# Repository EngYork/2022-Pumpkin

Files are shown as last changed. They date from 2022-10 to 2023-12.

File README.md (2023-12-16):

A Pumpkin-shaped lamp using WS2812b LED modules and the cheapest STM32 I could find on Digikey.

The timings are generated - and data fed fast enough - by using the DMA and abusing the SPI (See 2022 Pumpkin Code for details).

Due to component shortages the FTDI USB chip was never fitted or tested by me, although someone told me they tried it and it didn't work - so beware of that.

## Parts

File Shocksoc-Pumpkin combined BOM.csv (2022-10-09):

Standard
Source: | /home/david/Desktop/Pumpkin-main/Shocksoc-Pumpkin.kicad_sch
Date: | Wed 21 Sep 2022 12:20:54 BST
Tool: | Eeschema (6.0.7)
Generator: | /usr/share/kicad/plugins/bom_csv_grouped_by_value_with_fp.py
Component Count: | 44
Ref | Qnty | Value | Cmp name | Footprint | Description
C1, C3, C4, C7, | 4 | 10n | C | Capacitor_SMD:C_0805_2012Metric_Pad1.18x1.45mm_HandSolder | Unpolarized capacitor
C2, C8, | 2 | 1u | C | Capacitor_SMD:C_0805_2012Metric_Pad1.18x1.45mm_HandSolder | Unpolarized capacitor
C5, | 1 | 4u7 | C_Polarized | Capacitor_SMD:C_0805_2012Metric_Pad1.18x1.45mm_HandSolder | Polarized capacitor
D1, D2, D3, D4, D5, D6, D7, D8, D9, D10, D11, D12, D13, D14, D15, D16, D17, D18, D19, D20, | 20 | WS2813B | WS2813B_8 | LED_SMD:LED_WS2812_PLCC6_5.0x5.0mm_P1.6mm | RGB LED with integrated controller
J1, | 1 | USB_B_Micro | USB_B_Micro | Connector_USB:USB_Micro-B_Molex-105133-0001 | USB Micro Type B connector
J2, | 1 | Conn_01x03_Male | Conn_01x03_Male | Connector_PinHeader_2.54mm:PinHeader_1x03_P2.54mm_Vertical | Generic connector, single row, 01x03, script generated (kicad-library-utils/schlib/autogen/connector/)
J3, | 1 | Conn_01x02_Male | Conn_01x02_Male | Connector_PinHeader_2.54mm:PinHeader_1x02_P2.54mm_Vertical | Generic connector, single row, 01x02, script generated (kicad-library-utils/schlib/autogen/connector/)
J4, | 1 | Conn_ARM_JTAG_SWD_10 | Conn_ARM_JTAG_SWD_10 | Connector_PinHeader_1.27mm:PinHeader_2x05_P1.27mm_Vertical_SMD | Cortex Debug Connector, standard ARM Cortex-M SWD and JTAG interface
JP1, JP2, | 2 | SolderJumper_2_Open | SolderJumper_2_Open | Jumper:SolderJumper-2_P1.3mm_Open_RoundedPad1.0x1.5mm | Solder Jumper, 2-pole, open
Q1, | 1 | BSN20 | BSN20 | Package_TO_SOT_SMD:SOT-23 | 0.5A Id, 50V Vds, N-Channel MOSFET, SOT-23
R1, R2, R3, | 3 | 10k | R | Resistor_SMD:R_0805_2012Metric_Pad1.20x1.40mm_HandSolder | Resistor
SW1, SW2, SW3, SW4, | 4 | SW_Push | SW_Push | Button_Switch_SMD:SW_Push_1P1T_NO_6x6mm_H9.5mm | Push button switch, generic, two pins
U1, | 1 | AP2202K-3.3 | AP2204K-ADJ | Package_TO_SOT_SMD:SOT-23-5 | 150mA low dropout adjustable linear regulator, wide input voltage range, SOT-23-5 package
U2, | 1 | STM32L011F4Px | STM32L011F4Px | Package_SO:TSSOP-20_4.4x6.5mm_P0.65mm | ARM Cortex-M0+ MCU, 16KB flash, 2KB RAM, 32MHz, 1.65-3.6V, 16 GPIO, TSSOP-20
U3, | 1 | FT231XQ | FT231XQ | Package_DFN_QFN:QFN-20-1EP_4x4mm_P0.5mm_EP2.5x2.5mm | Full Speed USB to Full Handshake UART, QFN-20
RP2040
Source: | /home/david/Desktop/Pumpkin-rp2040/Shocksoc-Pumpkin.kicad_sch
Date: | Wed 21 Sep 2022 14:40:01 BST
Tool: | Eeschema (6.0.7)
Generator: | /usr/share/kicad/plugins/bom_csv_grouped_by_value_with_fp.py
Component Count: | 71
Ref | Qnty | Value | Cmp name | Footprint | Description | Vendor
C1, C3, C5, C7, | 4 | 10n | C | Capacitor_SMD:C_0805_2012Metric_Pad1.18x1.45mm_HandSolder | Unpolarized capacitor
C2, C4, | 2 | 1u | C | Capacitor_SMD:C_0805_2012Metric_Pad1.18x1.45mm_HandSolder | Unpolarized capacitor
C6, | 1 | 4u7 | C_Polarized | Capacitor_SMD:C_0805_2012Metric_Pad1.18x1.45mm_HandSolder | Polarized capacitor
C8, C9, | 2 | 20p | C | Capacitor_SMD:C_0603_1608Metric_Pad1.08x0.95mm_HandSolder | Unpolarized capacitor
C10, C11, | 2 | 1u | C | Capacitor_SMD:C_0603_1608Metric_Pad1.08x0.95mm_HandSolder | Unpolarized capacitor
D1, D2, D3, D4, D5, D6, D7, D8, D9, D10, D11, D12, D13, D14, D15, D16, D17, D18, D19, D20, | 20 | WS2813B | WS2813B_8 | LED_SMD:LED_WS2812_PLCC6_5.0x5.0mm_P1.6mm | RGB LED with integrated controller
J1, | 1 | USB_B_Micro | USB_B_Micro | Connector_USB:USB_Micro-B_Molex-105133-0001 | USB Micro Type B connector
J2, | 1 | Conn_ARM_JTAG_SWD_10 | Conn_ARM_JTAG_SWD_10 | Connector_PinHeader_1.27mm:PinHeader_2x05_P1.27mm_Vertical_SMD | Cortex Debug Connector, standard ARM Cortex-M SWD and JTAG interface
J3, | 1 | Conn_01x03_Male | Conn_01x03_Male | Connector_PinHeader_2.54mm:PinHeader_1x03_P2.54mm_Vertical_SMD_Pin1Left | Generic connector, single row, 01x03, script generated (kicad-library-utils/schlib/autogen/connector/)
J4, | 1 | Conn_01x02_Male | Conn_01x02_Male | Connector_PinHeader_2.54mm:PinHeader_1x02_P2.54mm_Vertical | Generic connector, single row, 01x02, script generated (kicad-library-utils/schlib/autogen/connector/)
JP1, JP2, | 2 | SolderJumper_2_Open | SolderJumper_2_Open | Jumper:SolderJumper-2_P1.3mm_Open_RoundedPad1.0x1.5mm | Solder Jumper, 2-pole, open
Q1, | 1 | BSN20 | BSN20 | Package_TO_SOT_SMD:SOT-23 | 0.5A Id, 50V Vds, N-Channel MOSFET, SOT-23
R1, R4, | 2 | 27 | R | Resistor_SMD:R_0603_1608Metric_Pad0.98x0.95mm_HandSolder | Resistor
R2, R3, | 2 | 10k | R | Resistor_SMD:R_0805_2012Metric_Pad1.20x1.40mm_HandSolder | Resistor
SW1, SW2, SW3, SW4, | 4 | SW_Push | SW_Push | Button_Switch_SMD:SW_Push_1P1T_NO_6x6mm_H9.5mm | Push button switch, generic, two pins
TP1, TP2, TP3, TP4, TP5, TP6, TP7, TP8, TP9, TP10, TP11, TP12, TP13, TP14, TP15, TP16, TP17, TP18, TP19, TP20, TP21, | 21 | TestPoint | TestPoint | TestPoint:TestPoint_Pad_D1.0mm | test point
U1, | 1 | AP2202K-3.3 | AP2204K-ADJ | Package_TO_SOT_SMD:SOT-23-5 | 150mA low dropout adjustable linear regulator, wide input voltage range, SOT-23-5 package
U3, | 1 | W25Q32JVSS | W25Q32JVSS | Package_SO:SOIC-8_5.23x5.23mm_P1.27mm | 32Mb Serial Flash Memory, Standard/Dual/Quad SPI, SOIC-8
U4, | 1 | RP2040 | RP2040 | Package_DFN_QFN:QFN-56-1EP_7x7mm_P0.4mm_EP3.2x3.2mm | A microcontroller by Raspberry Pi
Y1, | 1 | ABM8G-106-12.000MHZ-T | Crystal_GND24 | Crystal:Crystal_SMD_Abracon_ABM8G-4Pin_3.2x2.5mm | Four pin crystal, GND on pins 2 and 4
Combined (to produce 1 of each)
Quantity |  |  |  |  | Distributor Link
8 | 10n | C | Capacitor_SMD:C_0805_2012Metric_Pad1.18x1.45mm_HandSolder | Unpolarized capacitor
6 | 1u | C | Capacitor_SMD:C_0805_2012Metric_Pad1.18x1.45mm_HandSolder | Unpolarized capacitor
2 | 4u7 | C_Polarized | Capacitor_SMD:C_0805_2012Metric_Pad1.18x1.45mm_HandSolder | Polarized capacitor
2 | 20p | C | Capacitor_SMD:C_0603_1608Metric_Pad1.08x0.95mm_HandSolder | Unpolarized capacitor
40 | WS2813B | WS2813B_8 | LED_SMD:LED_WS2812_PLCC6_5.0x5.0mm_P1.6mm | RGB LED with integrated controller
2 | USB_B_Micro | USB_B_Micro | Connector_USB:USB_Micro-B_Molex-105133-0001 | USB Micro Type B connector
2 | Conn_01x03_Male | Conn_01x03_Male | Connector_PinHeader_2.54mm:PinHeader_1x03_P2.54mm_Vertical | Generic connector, single row, 01x03, script generated (kicad-library-utils/schlib/autogen/connector/)
2 | Conn_01x02_Male | Conn_01x02_Male | Connector_PinHeader_2.54mm:PinHeader_1x02_P2.54mm_Vertical | Generic connector, single row, 01x02, script generated (kicad-library-utils/schlib/autogen/connector/)
2 | Conn_ARM_JTAG_SWD_10 | Conn_ARM_JTAG_SWD_10 | Connector_PinHeader_1.27mm:PinHeader_2x05_P1.27mm_Vertical_SMD | Cortex Debug Connector, standard ARM Cortex-M SWD and JTAG interface
2 | 27 | R | Resistor_SMD:R_0603_1608Metric_Pad0.98x0.95mm_HandSolder | Resistor
5 | 10k | R | Resistor_SMD:R_0805_2012Metric_Pad1.20x1.40mm_HandSolder | Resistor
8 | SW_Push | SW_Push | Button_Switch_SMD:SW_Push_1P1T_NO_6x6mm_H9.5mm | Push button switch, generic, two pins
2 | AP2202K-3.3 | AP2204K-ADJ | Package_TO_SOT_SMD:SOT-23-5 | 150mA low dropout adjustable linear regulator, wide input voltage range, SOT-23-5 package
1 | STM32L011F4Px | STM32L011F4Px | Package_SO:TSSOP-20_4.4x6.5mm_P0.65mm | ARM Cortex-M0+ MCU, 16KB flash, 2KB RAM, 32MHz, 1.65-3.6V, 16 GPIO, TSSOP-20
1 | FT231XQ | FT231XQ | Package_DFN_QFN:QFN-20-1EP_4x4mm_P0.5mm_EP2.5x2.5mm | Full Speed USB to Full Handshake UART, QFN-20
1 | W25Q32JVSS | W25Q32JVSS | Package_SO:SOIC-8_5.23x5.23mm_P1.27mm | 32Mb Serial Flash Memory, Standard/Dual/Quad SPI, SOIC-8
1 | RP2040 | RP2040 | Package_DFN_QFN:QFN-56-1EP_7x7mm_P0.4mm_EP3.2x3.2mm | A microcontroller by Raspberry Pi
1 | ABM8G-106-12.000MHZ-T | Crystal_GND24 | Crystal:Crystal_SMD_Abracon_ABM8G-4Pin_3.2x2.5mm | Four pin crystal, GND on pins 2 and 4

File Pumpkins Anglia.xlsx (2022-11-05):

Part Number | Manufacturer | Description | Free Stock | Quantity Required | Prices
0805B103K500CT | WALSIN TECHNOLOGY CORPORATION | 0805 50V X7R 10NF 10% | 2974400 | 150 | QTY 50:£0.00421 ■ QTY 100:£0.00409 ■ QTY 150:£0.00397 ■ QTY 300:£0.00386 ■ QTY 1050:£0.00375 ■ QTY 2050:£0.00365 ■ QTY 4000+:£0.00356
0805F105Z160CT | WALSIN TECHNOLOGY CORPORATION | 0805 16V Y5V 1UF Z% | 43750 | 100 | QTY 50:£0.0073 ■ QTY 100:£0.00708 ■ QTY 150:£0.00688 ■ QTY 300:£0.00668 ■ QTY 1050:£0.0065 ■ QTY 2050:£0.00633 ■ QTY 4000+:£0.00616
0805X475K250CT | WALSIN TECHNOLOGY CORPORATION | 0805 25V X5R 4.7UF 10% | 365600 | 50 | QTY 50:£0.01232 ■ QTY 100:£0.01195 ■ QTY 150:£0.01161 ■ QTY 200:£0.01128 ■ QTY 550:£0.01097 ■ QTY 1050:£0.01068 ■ QTY 3000+:£0.0104
M50-3500542 | HARWIN | 05+05 DIL VERT PIN HDR | 24533 | 25 | QTY 1:£0.657 ■ QTY 1001:£0.644 ■ QTY 2001+:£0.618
DMN65D8L | DIODES ZETEX | SOT23 MOSFET BVDSS 41V-60V | 50 | 30 | QTY 1+:£0.01228
CR0805-JW-103ELF | BOURNS ELECTRONICS GMBH | 0805 5% 10K 1/8W | 124900 | 100 | QTY 50:£0.00289 ■ QTY 5050:£0.00263 ■ QTY 10050+:£0.00247
ST063DR | DIPTRONICS | SM 6MM RND SW 5.0BTN 320GF T/R | 12590 | 30 | QTY 1:£0.21196 ■ QTY 901:£0.20512 ■ QTY 1801:£0.19871 ■ QTY 2701:£0.13824 ■ QTY 3601+:£0.13248
AP2202K-3.3TRG1 | DIODES ZETEX | SOT25 LDO CMOS LOWCURR | 27200 | 30 | QTY 1:£0.12283 ■ QTY 3001:£0.1196 ■ QTY 6001+:£0.11654
STM32L010F4P6 | STMICROELECTRONICS | TSSOP20 ULP ARM CORTEX-M0+ MCU | 80 | 30 | QTY 1+:£0.83

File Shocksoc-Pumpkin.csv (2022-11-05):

Source: | /home/david/Desktop/Pumpkin/Shocksoc-Pumpkin.kicad_sch
Date: | Mon 10 Oct 2022 00:04:21 BST
Tool: | Eeschema (6.0.7)
Generator: | /usr/share/kicad/plugins/bom_csv_grouped_by_value_with_fp.py
Component Count: | 34
Ref | Qnty | Value | Cmp name | Footprint | Description | Vendor
C1, C3, C4, C7, | 4 | 10n | C | Capacitor_SMD:C_0805_2012Metric_Pad1.18x1.45mm_HandSolder | Unpolarized capacitor | https://www.anglia-live.com/products/product.aspx?catalogueref=1759736001
C2, C8, | 2 | 1u | C | Capacitor_SMD:C_0805_2012Metric_Pad1.18x1.45mm_HandSolder | Unpolarized capacitor | https://www.anglia-live.com/products/product.aspx?catalogueref=1759756001
C5, | 1 | 4u7 | C_Polarized | Capacitor_SMD:C_0805_2012Metric_Pad1.18x1.45mm_HandSolder |  | https://www.anglia-live.com/products/product.aspx?catalogueref=1759772001
D1, D2, D3, D4, D5, D6, D7, D8, D9, D10, | 10 | WS2813B | WS2813B_9 | Library:LED_WS2813_hand | RGB LED with integrated controller | https://www.digikey.co.uk/en/products/detail/seeed-technology-co-ltd/601000200/8120706
J1, | 1 | USB_B_Micro | USB_B_Micro | Connector_USB:USB_Micro-B_Molex-105133-0001 | USB Micro Type B connector | https://www.digikey.co.uk/en/products/detail/molex/1051330001/3313407
J2, | 1 | Conn_01x03_Male | Conn_01x03_Male | Connector_PinHeader_2.54mm:PinHeader_1x03_P2.54mm_Vertical | Generic connector, single row, 01x03, script generated (kicad-library-utils/schlib/autogen/connector/) | NA
J3, | 1 | Conn_01x02_Male | Conn_01x02_Male | Connector_PinHeader_2.54mm:PinHeader_1x02_P2.54mm_Vertical | Generic connector, single row, 01x02, script generated (kicad-library-utils/schlib/autogen/connector/) | NA
J4, | 1 | Conn_ARM_JTAG_SWD_10 | Conn_ARM_JTAG_SWD_10 | Connector_PinHeader_1.27mm:PinHeader_2x05_P1.27mm_Vertical | Cortex Debug Connector, standard ARM Cortex-M SWD and JTAG interface | https://www.anglia-live.com/products/product.aspx?catalogueref=1007956001
JP1, JP2, | 2 | SolderJumper_2_Open | SolderJumper_2_Open | Jumper:SolderJumper-2_P1.3mm_Open_RoundedPad1.0x1.5mm | Solder Jumper, 2-pole, open | NA
Q1, | 1 | BSN20 | BSN20 | Package_TO_SOT_SMD:SOT-23 | 0.5A Id, 50V Vds, N-Channel MOSFET, SOT-23 | https://www.anglia-live.com/products/product.aspx?catalogueref=981832001
R1, R2, R3, | 3 | 10k | R | Resistor_SMD:R_0805_2012Metric_Pad1.20x1.40mm_HandSolder | Resistor | https://www.anglia-live.com/products/product.aspx?catalogueref=608649001
SW1, SW2, SW3, SW4, | 4 | SW_Push | SW_Push | Button_Switch_SMD:SW_Push_1P1T_NO_6x6mm_H9.5mm | Push button switch, generic, two pins | https://www.anglia-live.com/products/product.aspx?catalogueref=335389001
U1, | 1 | AP2202K-3.3 | AP2204K-ADJ | Package_TO_SOT_SMD:SOT-23-5 | 150mA low dropout adjustable linear regulator, wide input voltage range, SOT-23-5 package | https://www.anglia-live.com/products/product.aspx?catalogueref=1055675001
U2, | 1 | STM32L011F4Px | STM32L011F4Px | Package_SO:TSSOP-20_4.4x6.5mm_P0.65mm | ARM Cortex-M0+ MCU, 16KB flash, 2KB RAM, 32MHz, 1.65-3.6V, 16 GPIO, TSSOP-20 | https://www.anglia-live.com/products/product.aspx?catalogueref=1836088001
U3, | 1 | FT231XQ | FT231XQ | Package_DFN_QFN:QFN-20-1EP_4x4mm_P0.5mm_EP2.5x2.5mm | Full Speed USB to Full Handshake UART, QFN-20

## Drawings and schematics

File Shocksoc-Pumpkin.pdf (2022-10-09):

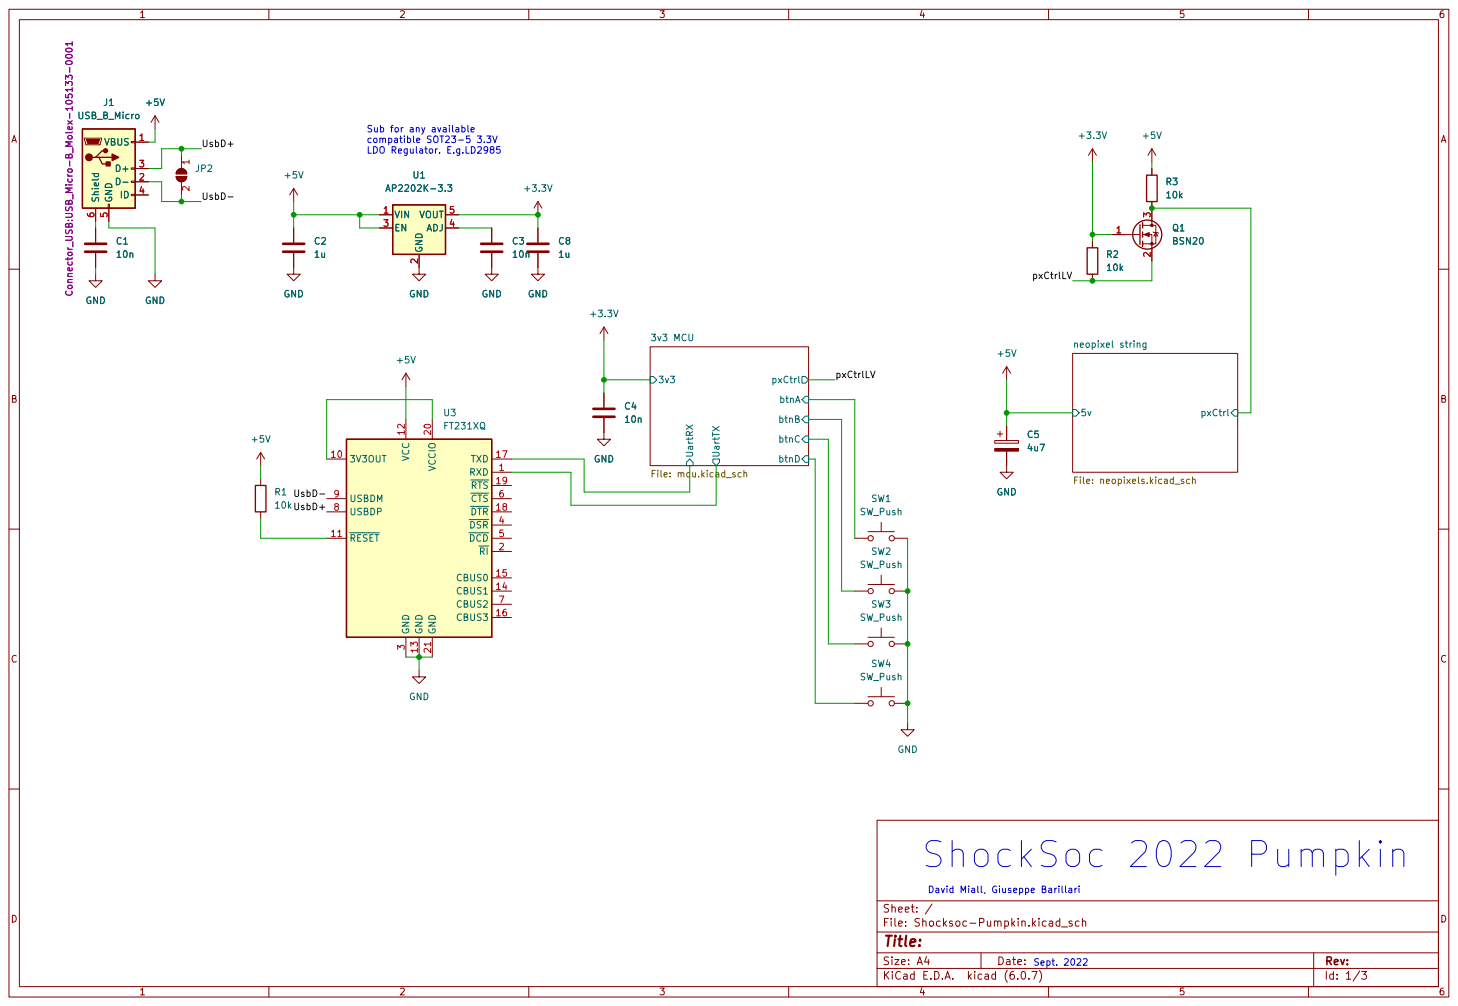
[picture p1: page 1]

Sub for any available
compatible SOT23-5 3.3V

3 ~{DSR} 4 ~{DCD} 5 ~{CTS} 6 CBUS2 7 USBDP 8 USBDM 9 U3FT231XQ

David Miall, Giuseppe Barillari

File: Shocksoc-Pumpkin.kicad_sch Sheet: /
Id: 1/3 Title:

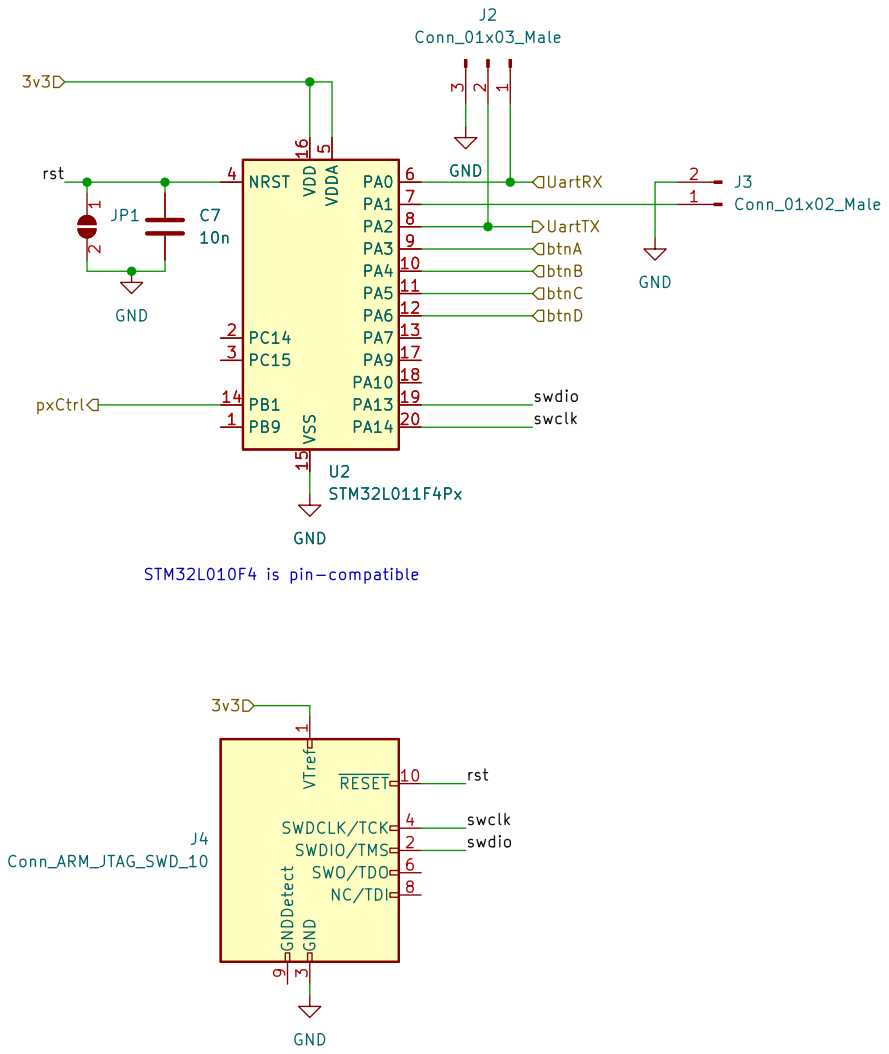
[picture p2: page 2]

3 SWDCLK/TCK 4 SWO/TDO 6 NC/TDI 8 GNDDetect 9

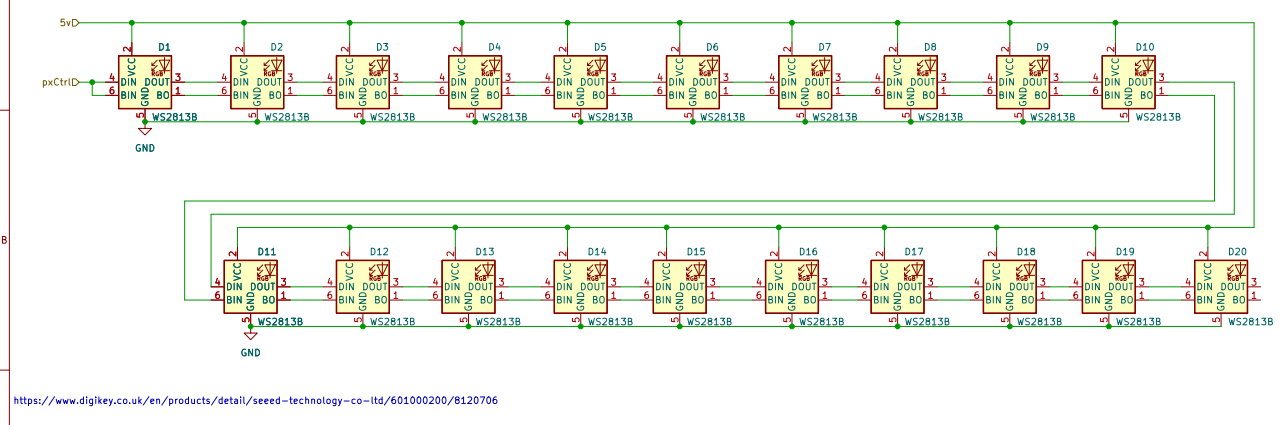
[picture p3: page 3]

https://www.digikey.co.uk/en/products/detail/seeed-technology-co-ltd/601000200/8120706 D11 WS2813B

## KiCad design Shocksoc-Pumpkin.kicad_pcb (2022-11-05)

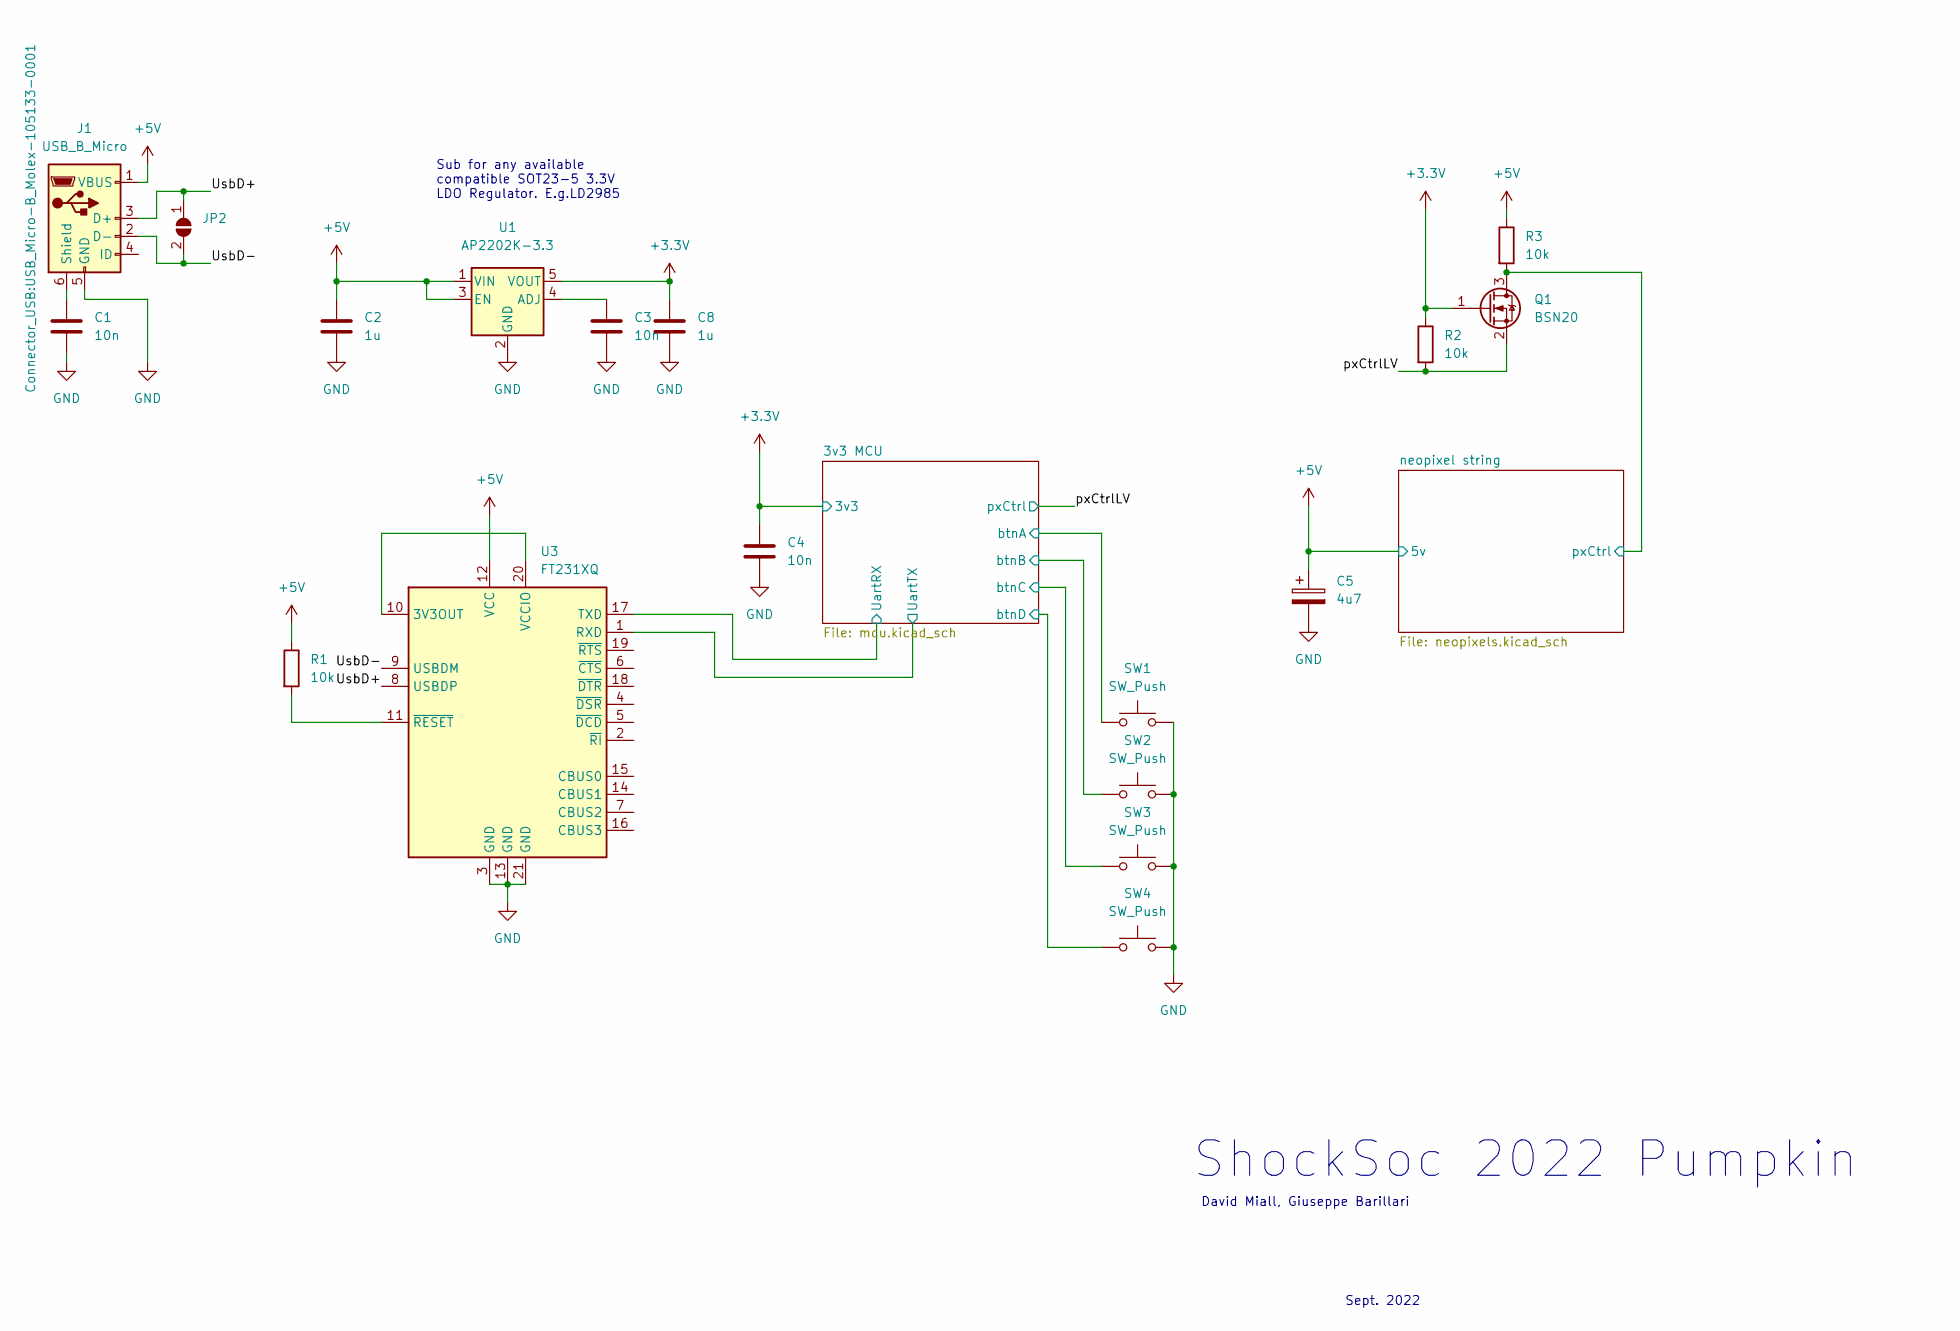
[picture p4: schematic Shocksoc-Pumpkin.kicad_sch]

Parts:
C1, C3, C4: 10n; C_0805_2012Metric_Pad1.18x1.45mm_HandSolder
C2, C8: 1u; C_0805_2012Metric_Pad1.18x1.45mm_HandSolder
C5: 4u7; C_0805_2012Metric_Pad1.18x1.45mm_HandSolder
J1: USB_B_Micro; USB_Micro-B_Molex-105133-0001
JP2: SolderJumper_2_Open; SolderJumper-2_P1.3mm_Open_RoundedPad1.0x1.5mm
Q1: BSN20; SOT-23
R1, R2, R3: 10k; R_0805_2012Metric_Pad1.20x1.40mm_HandSolder
SW1, SW2, SW3, SW4: SW_Push; SW_Push_1P1T_NO_6x6mm_H9.5mm
U1: AP2202K-3.3; SOT-23-5
U3: FT231XQ; QFN-20-1EP_4x4mm_P0.5mm_EP2.5x2.5mm

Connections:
+3.3V: C4.1, C8.1, Q1.1 (G), R2.1, U1.5 (VOUT); also elsewhere on the board
+5V: C2.1, C5.1, J1.1 (VBUS), R1.1, R3.1, U1.1 (VIN), U1.3 (EN), U3.12 (VCC); also elsewhere on the board
/3v3 MCU/UartRX: U3.17 (TXD); also elsewhere on the board
/3v3 MCU/UartTX: U3.1 (RXD); also elsewhere on the board
/3v3 MCU/btnA: SW1.1; also elsewhere on the board
/3v3 MCU/btnB: SW2.1; also elsewhere on the board
/3v3 MCU/btnC: SW3.1; also elsewhere on the board
/3v3 MCU/btnD: SW4.1; also elsewhere on the board
/UsbD+: J1.3 (D+), JP2.1 (A), U3.8 (USBDP)
/UsbD-: J1.2 (D-), JP2.2 (B), U3.9 (USBDM)
/neopixel string/pxCtrl: Q1.3 (D), R3.2; also elsewhere on the board
/pxCtrlLV: Q1.2 (S), R2.2; also elsewhere on the board
GND: C1.2, C2.2, C3.2, C4.2, C5.2, C8.2, J1.5 (GND), SW1.2, SW2.2, SW3.2, SW4.2, U1.2 (GND), U3.3 (GND), U3.13 (GND), U3.21 (GND); also elsewhere on the board
unnamed: C1.1, J1.6 (Shield)
unnamed: C3.1, U1.4 (ADJ)
unnamed: R1.2, U3.11 (~RESET)
unnamed: U3.10 (3V3OUT), U3.20 (VCCIO)

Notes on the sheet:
David Miall, Giuseppe Barillari
Sub for any available compatible SOT23-5 3.3V LDO Regulator. E.g.LD2985
ShockSoc 2022 Pumpkin
Sept. 2022

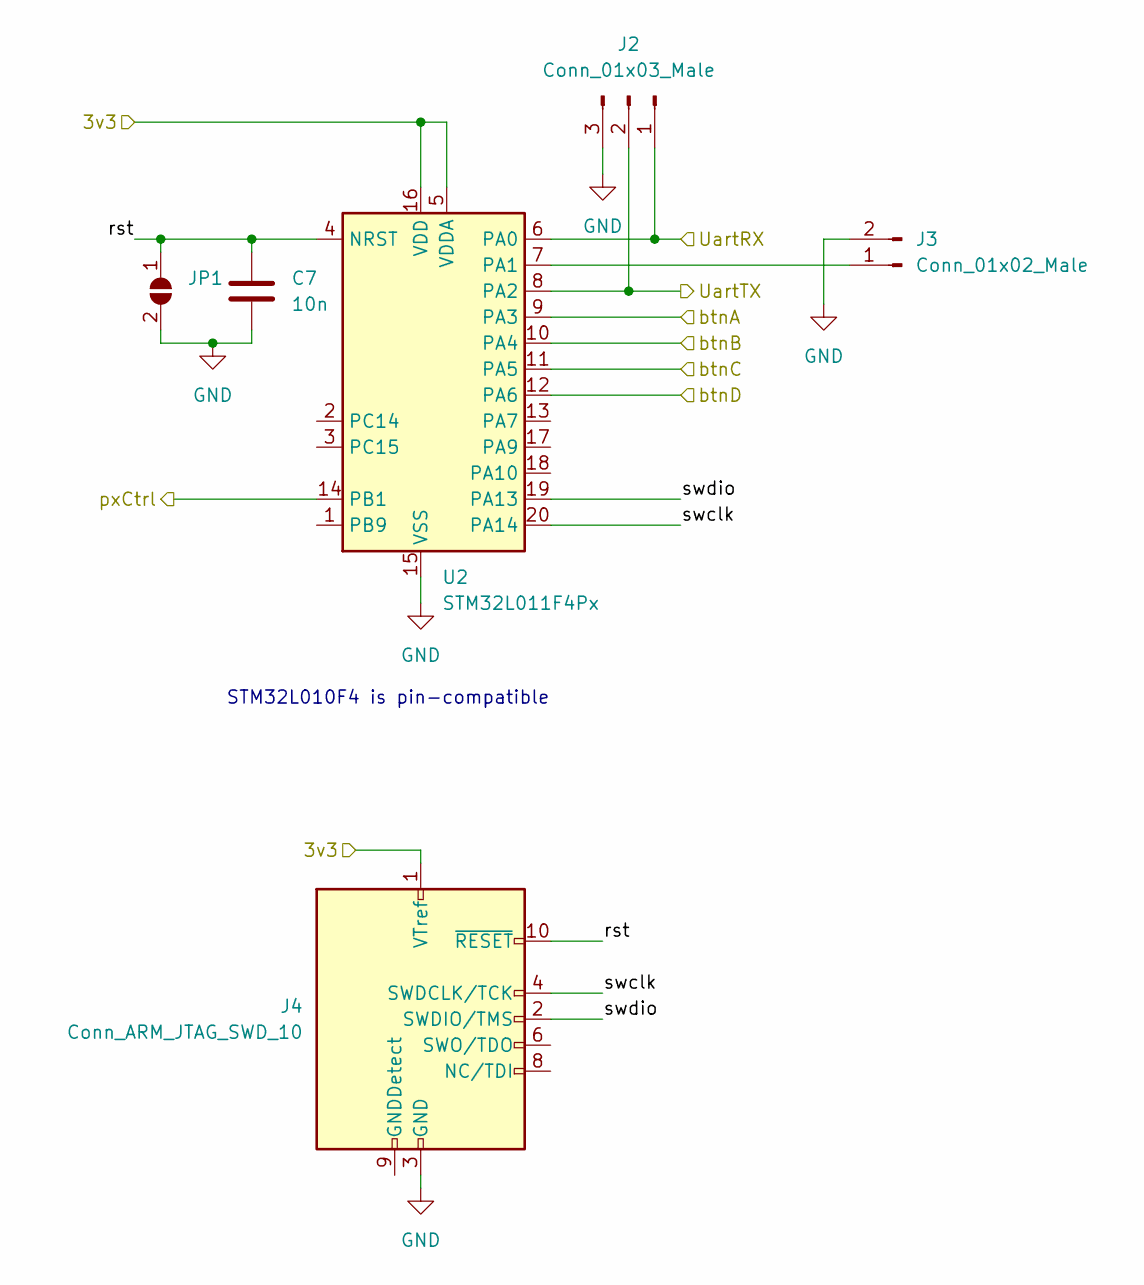
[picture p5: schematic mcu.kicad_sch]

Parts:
C7: 10n; C_0805_2012Metric_Pad1.18x1.45mm_HandSolder
J2: Conn_01x03_Male; PinHeader_1x03_P2.54mm_Vertical
J3: Conn_01x02_Male; PinHeader_1x02_P2.54mm_Vertical
J4: Conn_ARM_JTAG_SWD_10; PinHeader_2x05_P1.27mm_Vertical
JP1: SolderJumper_2_Open; SolderJumper-2_P1.3mm_Open_RoundedPad1.0x1.5mm
U2: STM32L011F4Px; TSSOP-20_4.4x6.5mm_P0.65mm

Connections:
+3.3V: J4.1 (VTref), U2.5 (VDDA), U2.16 (VDD); also elsewhere on the board
/3v3 MCU/UartRX: J2.1, U2.6 (PA0); also elsewhere on the board
/3v3 MCU/UartTX: J2.2, U2.8 (PA2); also elsewhere on the board
/3v3 MCU/btnA: U2.9 (PA3); also elsewhere on the board
/3v3 MCU/btnB: U2.10 (PA4); also elsewhere on the board
/3v3 MCU/btnC: U2.11 (PA5); also elsewhere on the board
/3v3 MCU/btnD: U2.12 (PA6); also elsewhere on the board
/3v3 MCU/rst: C7.1, J4.10 (~RESET), JP1.1 (A), U2.4 (NRST)
/3v3 MCU/swclk: J4.4 (SWDCLK/TCK), U2.20 (PA14)
/3v3 MCU/swdio: J4.2 (SWDIO/TMS), U2.19 (PA13)
/pxCtrlLV: U2.14 (PB1); also elsewhere on the board
GND: C7.2, J2.3, J3.2, J4.3 (GND), J4.5 (GND), JP1.2 (B), U2.15 (VSS); also elsewhere on the board
unnamed: J3.1, U2.7 (PA1)

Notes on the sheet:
STM32L010F4 is pin-compatible

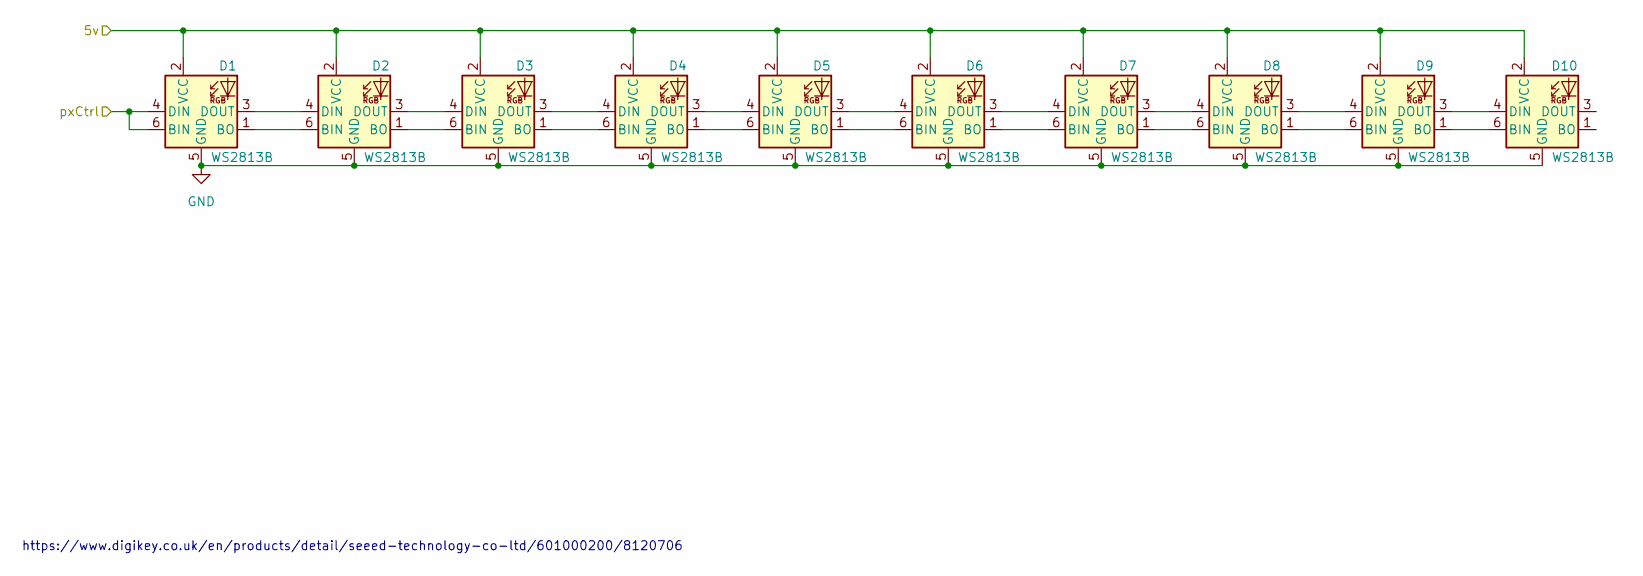
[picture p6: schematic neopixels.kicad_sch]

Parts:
D1, D2, D3, D4, D5, D6, D7, D8, D9, D10: WS2813B; LED_WS2813_hand

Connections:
+5V: D1.2 (VCC), D2.2 (VCC), D3.2 (VCC), D4.2 (VCC), D5.2 (VCC), D6.2 (VCC), D7.2 (VCC), D8.2 (VCC), D9.2 (VCC), D10.2 (VCC); also elsewhere on the board
/neopixel string/pxCtrl: D1.4 (DIN), D1.6 (BIN); also elsewhere on the board
GND: D1.5 (GND), D2.5 (GND), D3.5 (GND), D4.5 (GND), D5.5 (GND), D6.5 (GND), D7.5 (GND), D8.5 (GND), D9.5 (GND), D10.5 (GND); also elsewhere on the board
unnamed: D1.1 (BO), D2.6 (BIN)
unnamed: D1.3 (DOUT), D2.4 (DIN)
unnamed: D2.1 (BO), D3.6 (BIN)
unnamed: D2.3 (DOUT), D3.4 (DIN)
unnamed: D3.1 (BO), D4.6 (BIN)
unnamed: D3.3 (DOUT), D4.4 (DIN)
unnamed: D4.1 (BO), D5.6 (BIN)
unnamed: D4.3 (DOUT), D5.4 (DIN)
unnamed: D5.1 (BO), D6.6 (BIN)
unnamed: D5.3 (DOUT), D6.4 (DIN)
unnamed: D6.1 (BO), D7.6 (BIN)
unnamed: D6.3 (DOUT), D7.4 (DIN)
unnamed: D8.1 (BO), D9.6 (BIN)
unnamed: D8.3 (DOUT), D9.4 (DIN)
unnamed: D7.3 (DOUT), D8.4 (DIN)
unnamed: D7.1 (BO), D8.6 (BIN)
unnamed: D9.3 (DOUT), D10.4 (DIN)
unnamed: D9.1 (BO), D10.6 (BIN)

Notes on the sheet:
https://www.digikey.co.uk/en/products/detail/seeed-technology-co-ltd/601000200/8120706

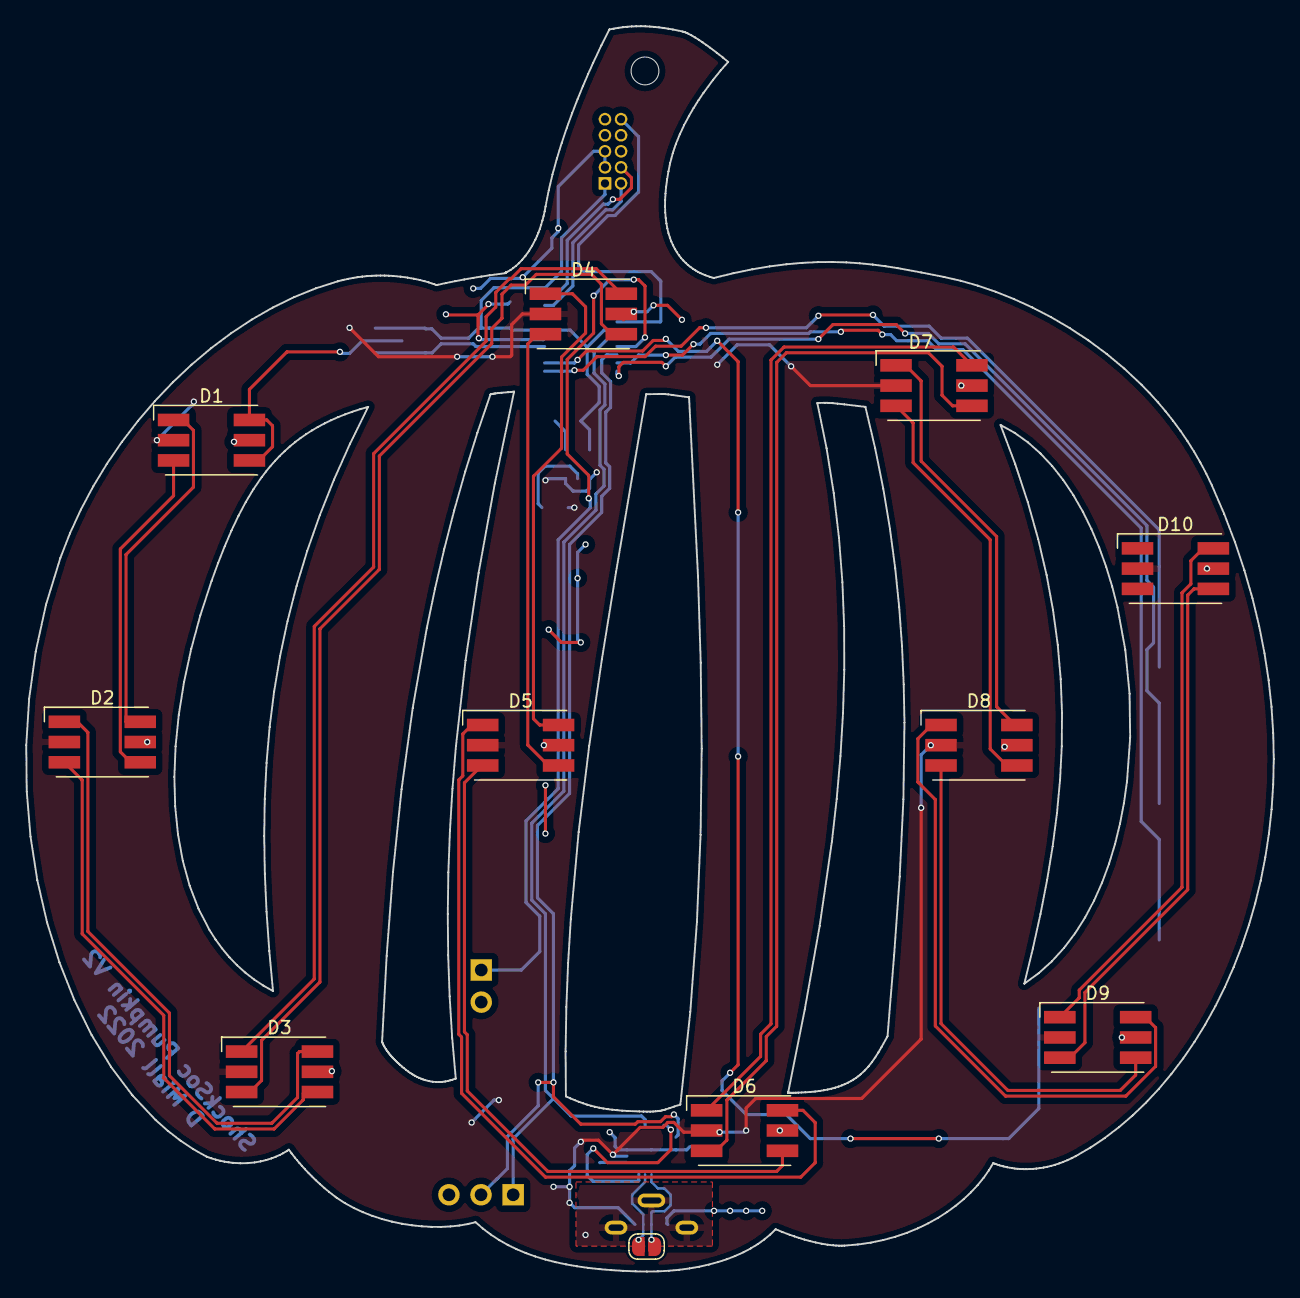
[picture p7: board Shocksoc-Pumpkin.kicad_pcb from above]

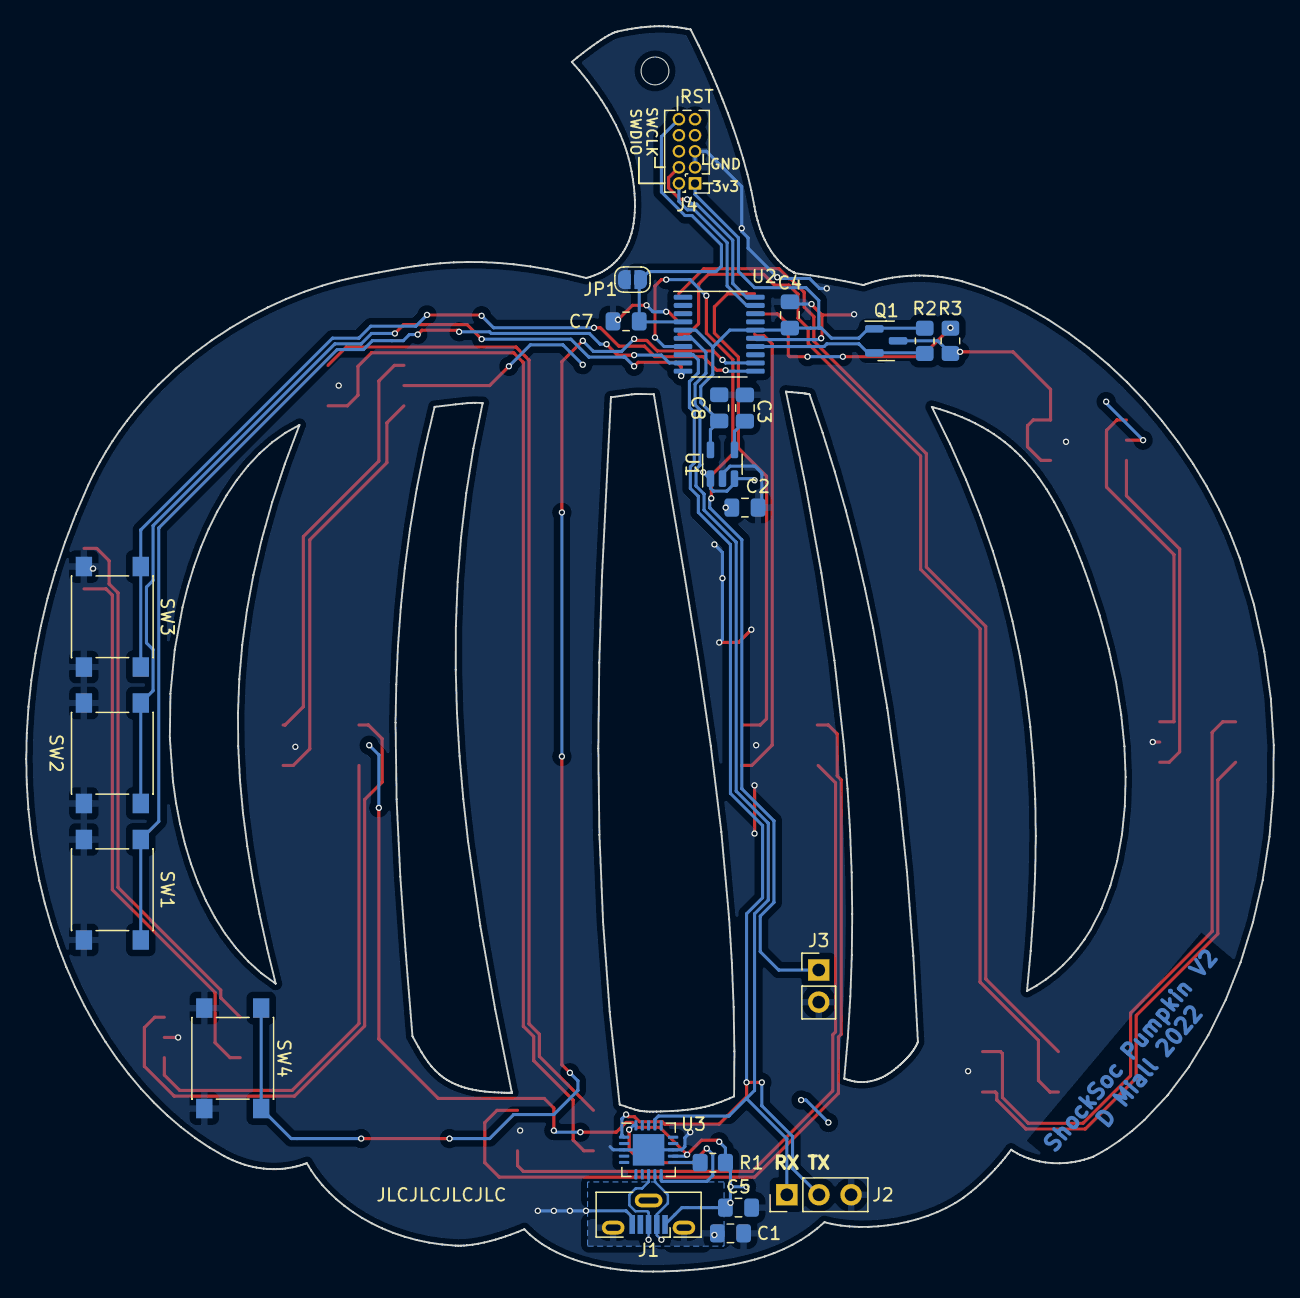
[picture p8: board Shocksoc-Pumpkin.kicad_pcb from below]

Board: 2 copper layers, 98.7 x 98.5 mm, 34 parts (23 on the bottom side), 39 nets.

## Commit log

2022-07-31 Initial charging sketch
    [Shocksoc-Pumpkin.kicad_pcb, Shocksoc-Pumpkin.kicad_sch]
2022-10-09 Add current files
    [Shocksoc-Pumpkin combined BOM.csv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]
2022-10-09 Resized pads
    [Shocksoc-Pumpkin.kicad_pcb]
2022-10-09 Add THT debug
    [Shocksoc-Pumpkin-B_Cu.gbr, Shocksoc-Pumpkin-B_Mask.gbr, Shocksoc-Pumpkin-B_Paste.gbr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]
